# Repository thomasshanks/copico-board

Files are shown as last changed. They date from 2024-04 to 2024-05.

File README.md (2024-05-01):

# CoPiCo PCB KiCad Files

The CoPiCo is a cartridge for the Tandy Color Computer that adds WiFi to and
serves as a boot ROM for the system. It is based on the Raspberry Pi Pico W
microcontroller dev board, which includes onboard WiFi.

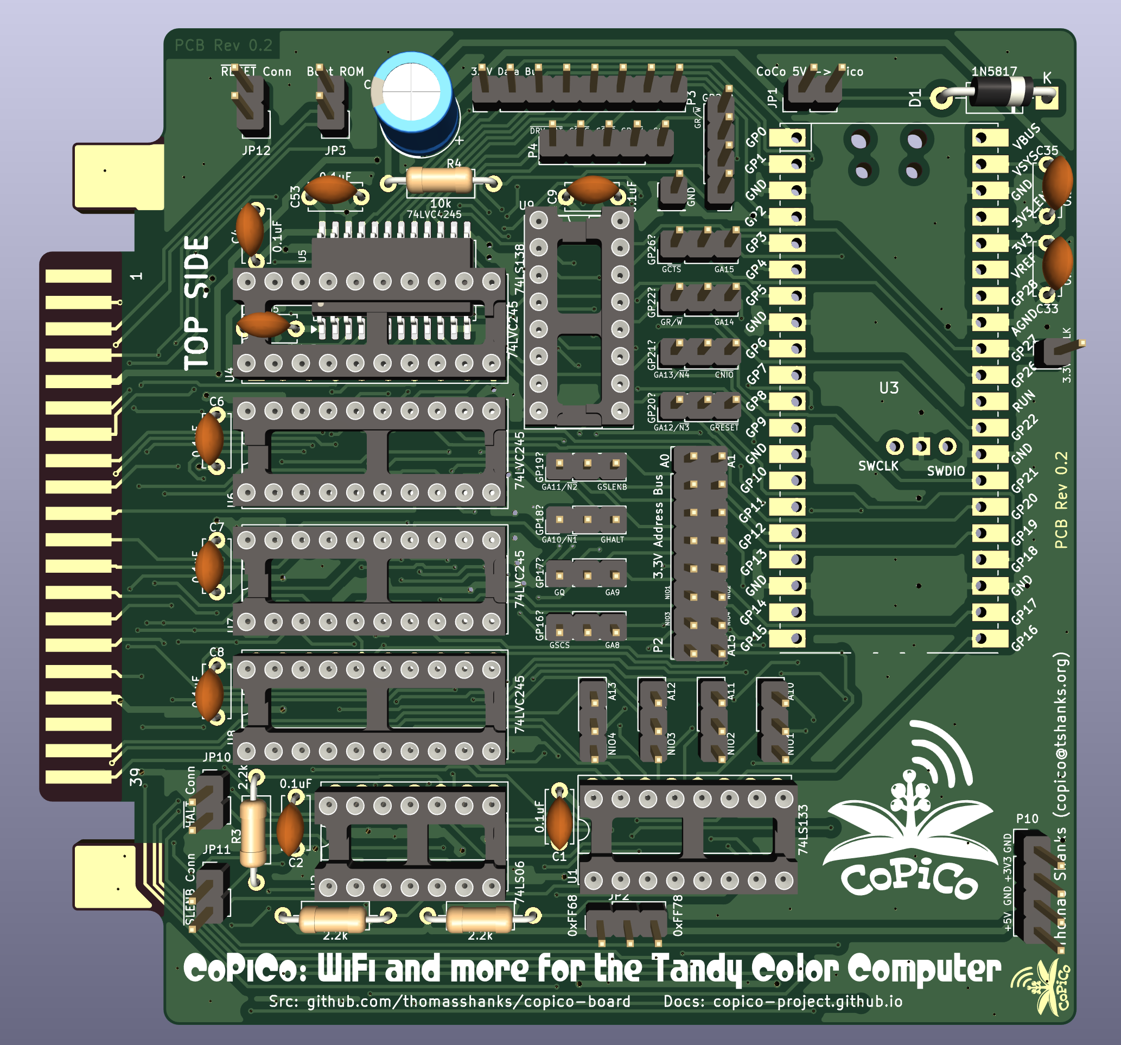
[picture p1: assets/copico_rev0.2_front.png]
copico_rev0.2_front


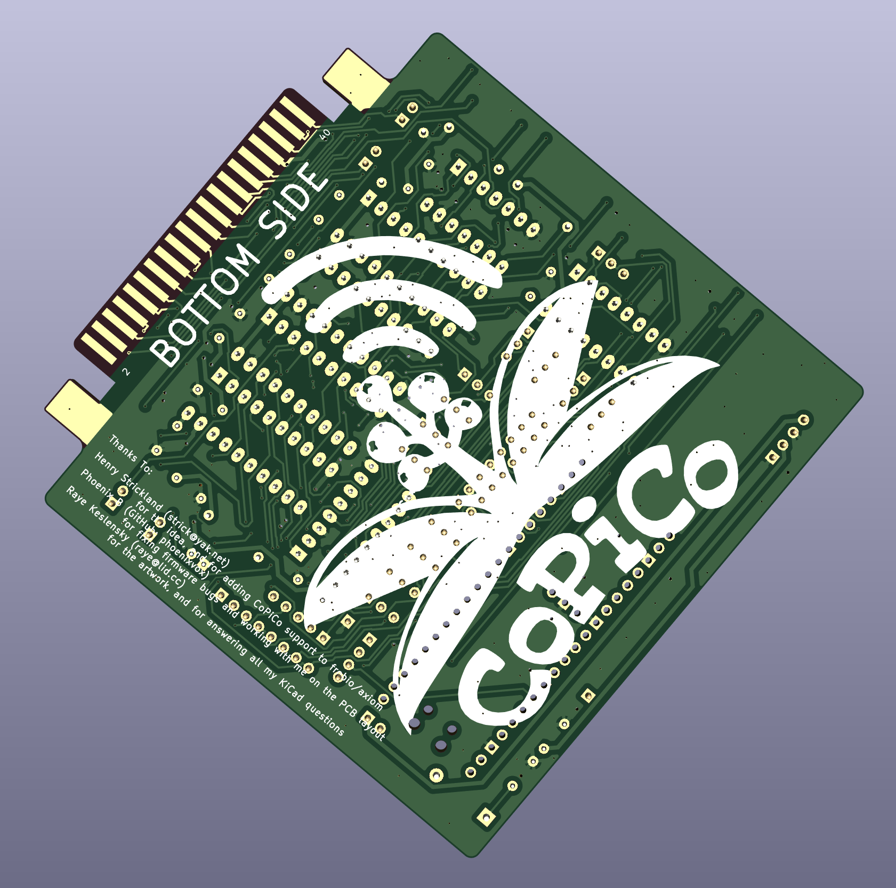
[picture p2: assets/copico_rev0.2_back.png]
copico_rev0.2_back


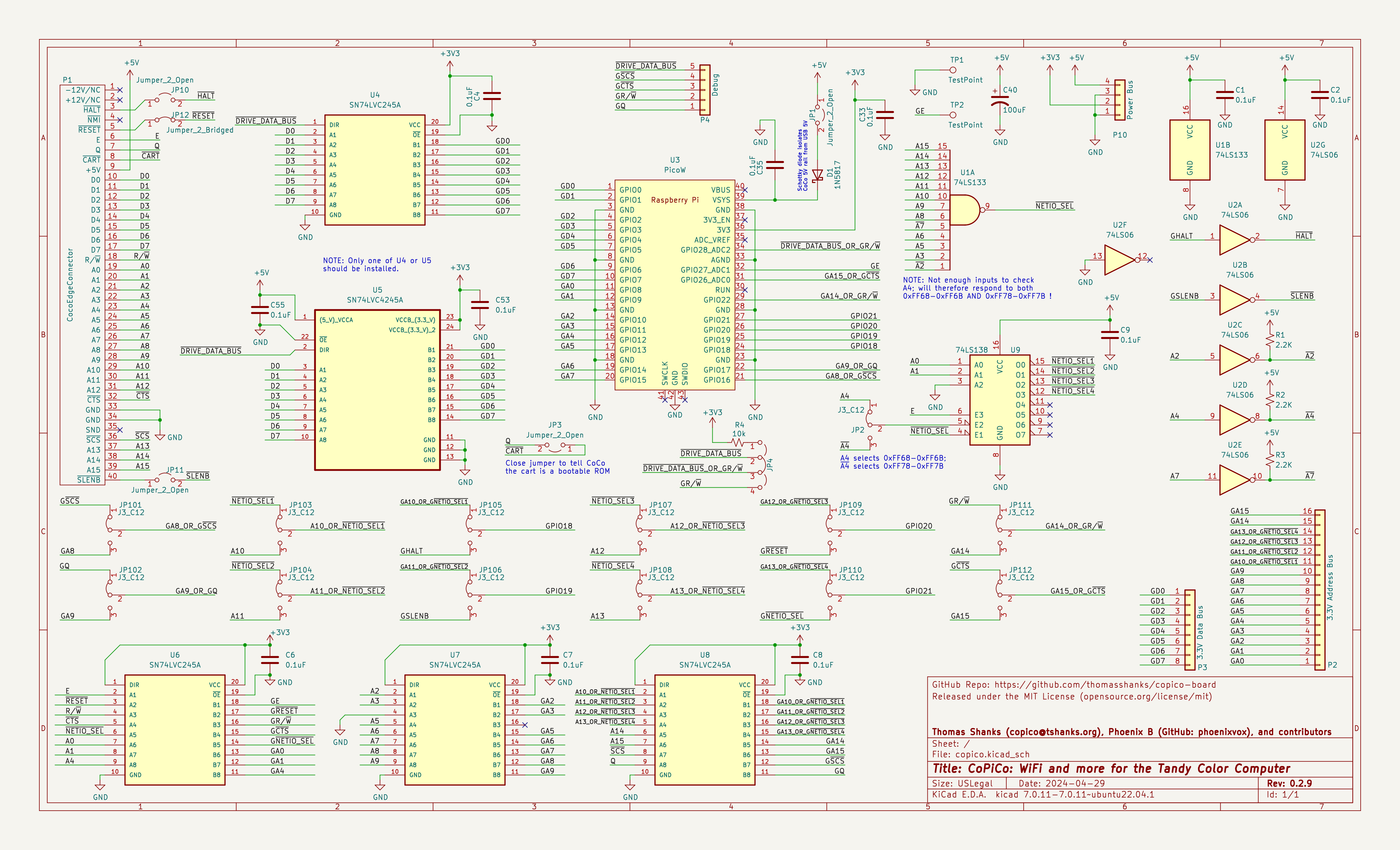
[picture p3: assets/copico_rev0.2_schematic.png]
copico_rev0.2_schematic

[copico_rev0.2_schematic_v0.2.9.pdf](assets/copico_rev0.2_schematic_v0.2.9.pdf)

## WiFi Connectivity

The firmware (see 'copico-firmware' repo) will behave more like a SPI WiFi
module or the WizNet chip (or perhaps both, depending on mode). It will, of
course, also allow listing and connecting to the desired WiFi network.

## ROM Emulation

CoPiCo will also support boot ROM emulation (initially just for a 1 KB ROM due
to limitations of first revision of the CoPiCo PCB). Henry Strickland
(@strickyak) plans to use this feature to load a version of his
"axiom" network boot ROM (see
https://github.com/strickyak/frobio/tree/main/frob3/booting).

## Other Future Capabilities

Future capabilities for the CoPiCo may include:
- VGA or HDMI output based on the captured contents of video RAM
- Logic capture / bus trace
- Remote debug, with breakpoints and watchpoints

## Stay Tuned to This Channel

Please star this repo and/or watch this space for updates as development
continues!

Thank you for being a part of the Retrocomputing community!

Thomas Shanks (copico@tshanks.org)

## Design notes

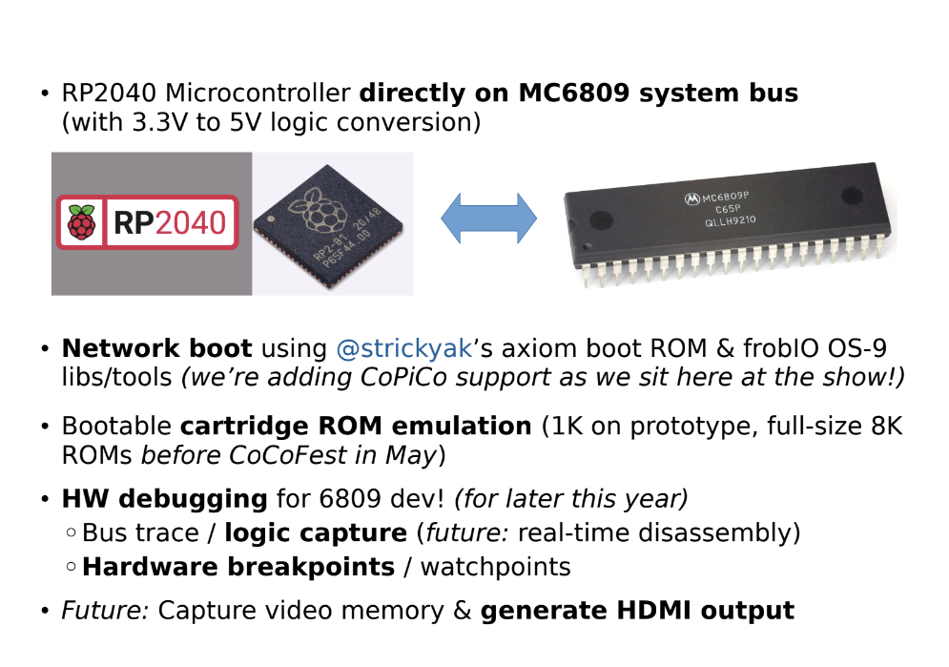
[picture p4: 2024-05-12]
assets/copico_slide.png

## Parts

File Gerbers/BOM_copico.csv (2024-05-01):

Ref | Qnty | Value | Cmp name | Footprint | Description | Vendor | Part
C1, C2, C4, C5, C8, C9, C33, C35, C73, C75 | 10 | 0.1uF | C | Capacitor_THT:C_Disc_D5.0mm_W2.5mm_P5.00mm | Ceramic THT Capacitor | AVX | SR215C104MAA
C40 | 1 | 100uF | C_Polarized | Capacitor_THT:CP_Radial_D7.5mm_P2.50mm | Electrolytic THT Capacitor | Panasonic | 16SEPC100MW
D1 | 1 |  | 1N5817 | Diode_THT:D_DO-41_SOD81_P10.16mm_Horizontal | 20V 1A Schottky Barrier Rectifier Diode, DO-41 | Major Brands | 1N5817
JP1, JP3, JP10, JP11 | 4 | Open | DIP_Jumper_Header_1x2 | Connector_PinHeader_2.54mm:PinHeader_1x02_P2.54mm_Vertical | Header, 100mil, single row, 1x2 | Jameco ValuePro | PH20-140S-6T
JP12 | 1 | Bridged12 | DIP_Jumper_Header_1x2 | Connector_PinHeader_2.54mm:PinHeader_1x02_P2.54mm_Vertical | Header, 100mil, single row, 1x2 | Jameco ValuePro | PH20-140S-6T
JP2, JP101, JP102, JP103, JP104, JP105, JP106, JP107, JP108, JP109, JP110, JP111, JP112 | 13 | Bridged12 | DIP_Jumper_Header_1x3 | Connector_PinHeader_2.54mm:PinHeader_1x03_P2.54mm_Vertical | Header, 100mil, single row, 1x3 | Jameco ValuePro | PH20-140S-6T
JP4 | 1 | Bridged23 | DIP_Jumper_Header_1x4 | Connector_PinHeader_2.54mm:PinHeader_1x04_P2.54mm_Vertical | Header, 100mil, single row, 1x4 | Jameco ValuePro | PH20-140S-6T
JP1, JP2, JP3, JP4, JP4, JP10, JP11, JP12, JP101, JP102, JP103, JP104, JP105, JP106, JP107, JP108, JP109, JP110, JP111, JP112 | 20 |  | DIP_Jumper_2_Pin | None | Plastic Jumper, 2-pin, 100mil DIP Spacing | TE Connectivity | 881545-1
P1 | 1 |  | DIP_Header_1x16 | Connector_PinHeader_2.54mm:PinHeader_1x16_P2.54mm_Vertical | Header, 100mil, single row, 1x16 | Jameco ValuePro | PH20-140S-6T
P2, P3 | 2 |  | DIP_Header_1x8 | Connector_PinHeader_2.54mm:PinHeader_1x08_P2.54mm_Vertical | Header, 100mil, single row, 1x8 | Jameco ValuePro | PH20-140S-6T
P4 | 1 |  | DIP_Header_1x5 | Connector_PinHeader_2.54mm:PinHeader_1x05_P2.54mm_Vertical | Header, 100mil, single row, 1x5 | Jameco ValuePro | PH20-140S-6T
P10 | 1 |  | DIP_Header_1x4 | Connector_PinHeader_2.54mm:PinHeader_1x04_P2.54mm_Vertical | Header, 100mil, single row, 1x4 | Jameco ValuePro | PH20-140S-6T
R1, R2, R3 | 3 | 2.2K | R_Small | Resistor_THT:R_Axial_DIN0207_L6.3mm_D2.5mm_P10.16mm_Horizontal | Resistor, 0.25W, Axial | Jameco ValuePro | CF1/4W222JRC
R4 | 1 | 10k | R_Small | Resistor_THT:R_Axial_DIN0207_L6.3mm_D2.5mm_P10.16mm_Horizontal | Resistor, 0.25W, Axial | Jameco ValuePro | RC0410K0JT
TP1, TP2 | 2 |  | DIP_Header_1x1 | Connector_PinHeader_2.54mm:PinHeader_1x01_P2.54mm_Vertical | Header, 100mil, single row, 1x1 | Jameco ValuePro | PH20-140S-6T
U1 | 1 |  | 74LS133N | Package_DIP:DIP-16_W7.62mm_LongPads | NAND 13-input | Motorola | SN74LS133N
U1, U9 | 2 |  | DIP-16_W300_Socket | Package_DIP:DIP-16_W7.62mm_LongPads |  | Jameco ValuePro | ICS-316-T
U2 | 1 |  | 74LS06N | Package_DIP:DIP-14_W7.62mm_LongPads | Inverter Open Collect | Major Brands | 74LS06N
U2 | 1 |  | DIP-14_W300_Socket | Package_DIP:DIP-14_W7.62mm_LongPads |  | Jameco ValuePro | ICS-314-T
U3 | 1 |  | PicoWH | RPi_Pico:RPi_PicoW_SMD_TH | RPi Pico W | RPi | Pico W
U3, U3 | 2 |  | DIP_Header_1x20 | Connector_PinHeader_2.54mm:PinHeader_1x20_P2.54mm_Vertical | Header, 100mil, single row, 1x20 | Jameco ValuePro | PH20-140S-6T
U3, U3 | 2 |  | SIP-20_Socket | Package_SIP:SIP-20_LongPads |  | Jameco ValuePro | G85-20-R
U4, U6, U7, U8 | 4 |  | SN74LVC245AN | Package_DIP:DIP-20_W7.62mm_LongPads |  | TI | SN74LVC245AN
U4, U6, U7, U8 | 4 |  | DIP-20_W300_Socket | Package_DIP:DIP-20_W7.62mm_LongPads |  | Adam Tech | ICS-320-T
U5 | 1 |  | SN74LVC4245A | Package_SO:SOIC-24W_7.5x15.4mm_P1.27mm |  | TI | SN74LVC4245ADWR
U9 | 1 |  | 74LS138N | Package_DIP:DIP-16_W7.62mm_LongPads | Decoder 3 to 8 active low outputs | TI | SN74LS138N

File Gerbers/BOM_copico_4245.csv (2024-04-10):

designator | quantity | value | pkg | desc | mpn | mount_type
C1, C2, C32, C4, C5, C73, C75, C8 | 8 | 0.1uF | C_Disc_D5.0mm_W2.5mm_P5.00mm | Ceramic Radial 0.1uF 10% 25+V LS:5mm |  | tht
C31 | 1 | 4.7uF | C_Rect_L5.0mm_W3.2mm_H5.00mm | Ceramic Radial 4.7uF 10% 25+V LS:5mm | FG28X5R1E475KRT06 | tht
C40 | 1 | 100uF | CP_Radial_D7.5mm_P2.50mm | Electrolytic Radial 100uF 20% 5000hr LS:2.5mm | ESL107M035AE3AA | tht
JP1, JP3 | 2 | 8JP2NC | PinHeader_2x08_P2.54mm_Vertical | M 2.54mm Header |  | tht
JP2 | 1 | J3_C12 | PinHeader_1x03_P2.54mm_Vertical | M 2.54mm Header |  | tht
P10 | 1 | Power Bus | PinHeader_1x04_P2.54mm_Vertical | M 2.54mm Header |  | tht
P2 | 1 | 5V Data Bus | PinHeader_1x08_P2.54mm_Vertical | M 2.54mm Header |  | tht
P3 | 1 | 3.3V Data Bus | PinHeader_1x08_P2.54mm_Vertical | M 2.54mm Header |  | tht
P4 | 1 | 5V Address Bus | PinHeader_1x16_P2.54mm_Vertical | M 2.54mm Header |  | tht
P5 | 1 | 3.3V Address Bus | PinHeader_1x16_P2.54mm_Vertical | M 2.54mm Header |  | tht
R1, R2 | 2 | 4.7k | R_Axial_DIN0207_L6.3mm_D2.5mm_P10.16mm_Horizontal | Film Resistor Axial 1/4w 5% |  | tht
U1 | 1 | DIP-16 SKT | DIP-16_W7.62mm_LongPads | 16P DUAL WIPE DIPSKT | 4816-3000-CP | tht
U2 | 1 | DIP-14 SKT | DIP-14_W7.62mm_LongPads | 14P DUAL WIPE DIPSKT | 4814-3000-CP | tht
U3 | 2 | 2ea / SIP-20 SKT | SIP-20_LongPads | PAIR OF STANDRD SOLDER TAIL SIP SOCKETS 5mm Height |  | tht
U4, U5, U8 | 3 | DIP-20 SKT | DIP-20_W7.62mm_LongPads | 20P DUAL WIPE DIPSKT |  | tht
U6 | 1 | dnp | dnp | dnp |  | tht
U7 | 1 | 74LVC4245A | SOIC127P1030X265-24N | Bus Transceivers Octal Bus Trncvr & 3.3-5V W/3-St Otpt | SN74LVC4245ADWR | tht

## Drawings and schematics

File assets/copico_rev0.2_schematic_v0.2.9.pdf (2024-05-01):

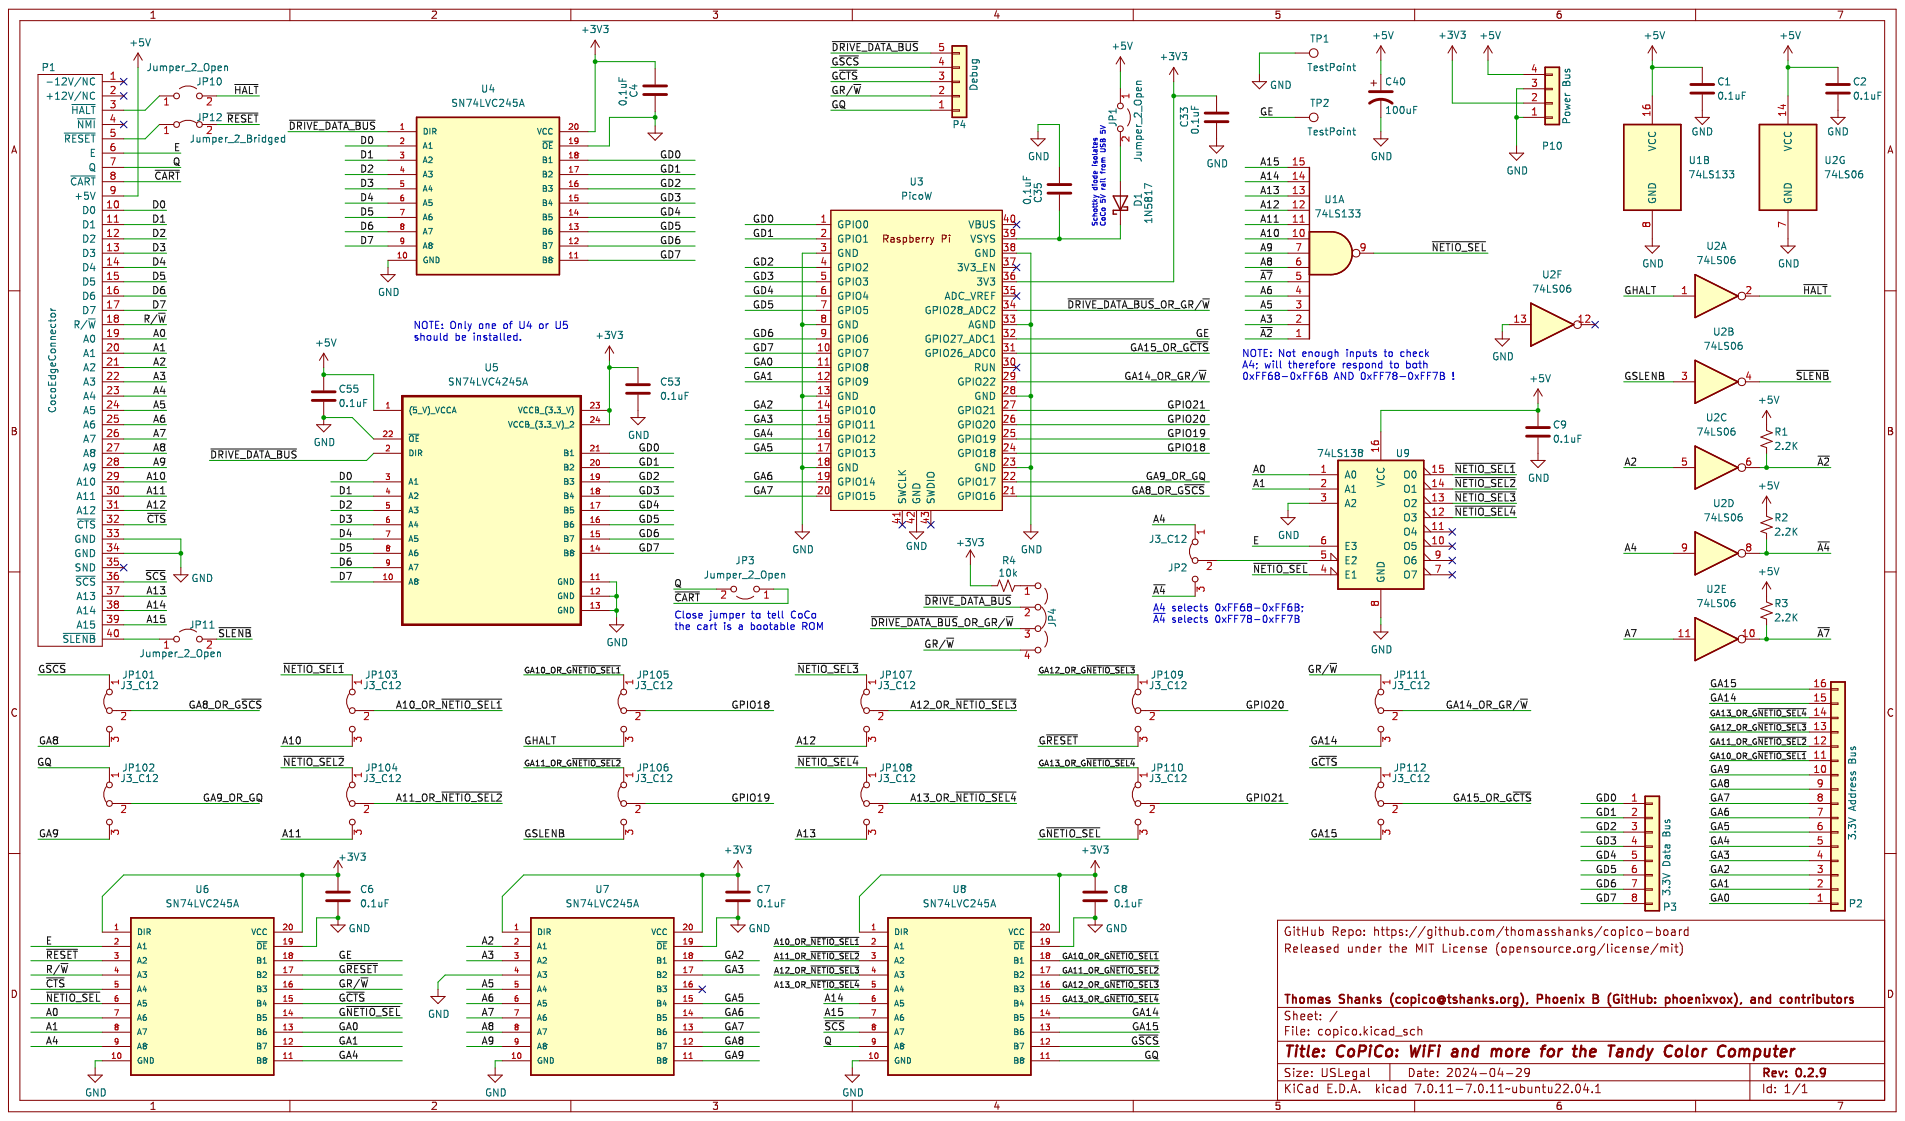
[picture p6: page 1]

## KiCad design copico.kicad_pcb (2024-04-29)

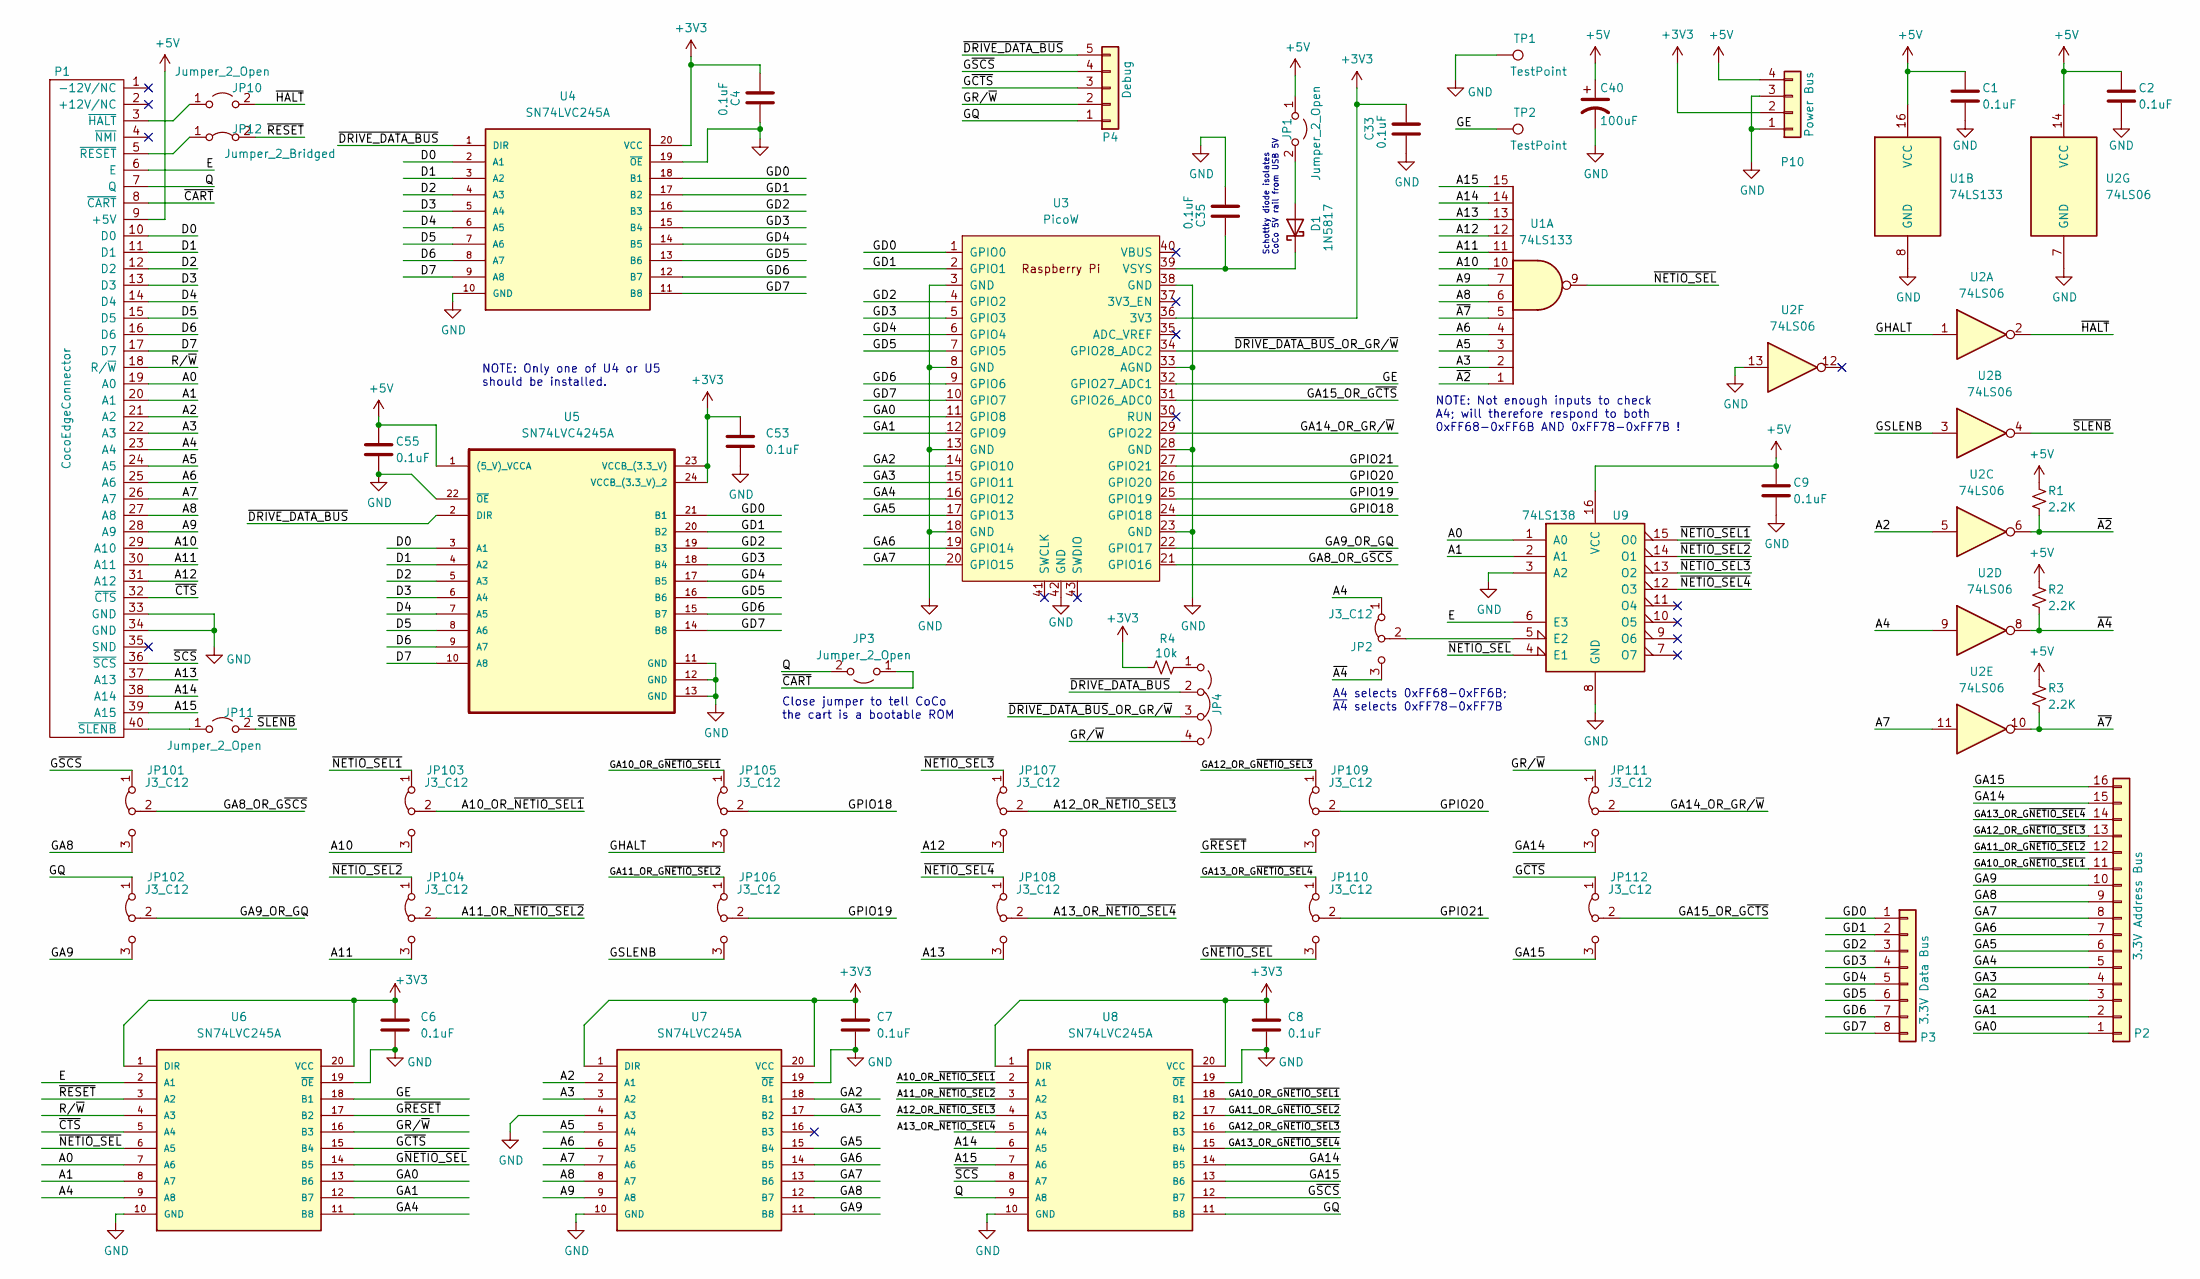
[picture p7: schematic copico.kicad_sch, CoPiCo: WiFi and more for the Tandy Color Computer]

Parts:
C1, C2, C4, C6, C7, C8, C9, C33, C35, C53, C55: 0.1uF; C_Disc_D5.0mm_W2.5mm_P5.00mm
C40: 100uF; CP_Radial_D7.5mm_P2.50mm
D1: 1N5817; D_DO-41_SOD81_P10.16mm_Horizontal
JP1, JP3, JP10, JP11: Jumper_2_Open; PinHeader_1x02_P2.54mm_Vertical
JP2, JP101, JP102, JP103, JP104, JP105, JP106, JP107, JP108, JP109, JP110, JP111, JP112: J3_C12; PinHeader_1x03_P2.54mm_Vertical
JP4: jp_ser_4pin_23cl; PinHeader_1x04_P2.54mm_Vertical
JP12: Jumper_2_Bridged; PinHeader_1x02_P2.54mm_Vertical
P1: CocoEdgeConnector; CocoCardEdge
P2: 3.3V Address Bus; PinHeader_1x16_P2.54mm_Vertical
P3: 3.3V Data Bus; PinHeader_1x08_P2.54mm_Vertical
P4: Debug; PinHeader_1x05_P2.54mm_Vertical
P10: Power Bus; PinHeader_1x04_P2.54mm_Vertical
R1, R2, R3: 2.2K; R_Axial_DIN0207_L6.3mm_D2.5mm_P10.16mm_Horizontal
R4: 10k; R_Axial_DIN0207_L6.3mm_D2.5mm_P10.16mm_Horizontal
TP1, TP2: TestPoint; PinHeader_1x01_P2.54mm_Vertical
U1: 74LS133; DIP-16_W7.62mm_LongPads
U2: 74LS06; DIP-14_W7.62mm_LongPads
U3: PicoW; RPi_PicoW_SMD_TH
U4, U6, U7, U8: SN74LVC245A; DIP20-2.54-26.2X7.62MM; MPN SN74LVC245AN
U5: SN74LVC4245A; SOIC-24W_7.5x15.4mm_P1.27mm
U9: 74LS138; DIP-16_W7.62mm_LongPads

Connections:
+3V3: C4.2, C6.1, C7.1, C8.1, C33.1, C53.1, P10.2, R4.1, U3.36 (3V3), U4.20 (VCC), U5.23 (VCCB_(3.3_V)), U5.24 (VCCB_(3.3_V)_2), U6.1 (DIR), U6.20 (VCC), U7.1 (DIR), U7.20 (VCC), U8.1 (DIR), U8.20 (VCC)
+5V: C1.1, C2.1, C9.1, C40.1, C55.1, JP1.1 (A), P1.9 (+5V), P10.4, R1.1, R2.1, R3.1, U1.16 (VCC), U2.14 (VCC), U5.1 ((5_V)_VCCA), U9.16 (VCC)
/A0: P1.19 (A0), U6.7 (A6), U9.1 (A0)
/A1: P1.20 (A1), U6.8 (A7), U9.2 (A1)
/A2: P1.21 (A2), U2.5, U7.2 (A1)
/A3: P1.22 (A3), U1.2, U7.3 (A2)
/A4: JP2.1 (A), P1.23 (A4), U2.9, U6.9 (A8)
/A5: P1.24 (A5), U1.3, U7.5 (A4)
/A6: P1.25 (A6), U1.4, U7.6 (A5)
/A7: P1.26 (A7), U2.11, U7.7 (A6)
/A8: P1.27 (A8), U1.6, U7.8 (A7)
/A9: P1.28 (A9), U1.7, U7.9 (A8)
/A10: JP103.3 (B), P1.29 (A10), U1.10
/A10_OR_~NETIO_SEL1: JP103.2 (C), U8.2 (A1)
/A11: JP104.3 (B), P1.30 (A11), U1.11
/A11_OR_~NETIO_SEL2: JP104.2 (C), U8.3 (A2)
/A12: JP107.3 (B), P1.31 (A12), U1.12
/A12_OR_~NETIO_SEL3: JP107.2 (C), U8.4 (A3)
/A13: JP108.3 (B), P1.37 (A13), U1.13
/A13_OR_~NETIO_SEL4: JP108.2 (C)
/A14: P1.38 (A14), U1.14, U8.6 (A5)
/A15: P1.39 (A15), U1.15, U8.7 (A6)
/D0: P1.10 (D0), U4.2 (A1), U5.3 (A1)
/D1: P1.11 (D1), U4.3 (A2), U5.4 (A2)
/D2: P1.12 (D2), U4.4 (A3), U5.5 (A3)
/D3: P1.13 (D3), U4.5 (A4), U5.6 (A4)
/D4: P1.14 (D4), U4.6 (A5), U5.7 (A5)
/D5: P1.15 (D5), U4.7 (A6), U5.8 (A6)
/D6: P1.16 (D6), U4.8 (A7), U5.9 (A7)
/D7: P1.17 (D7), U4.9 (A8), U5.10 (A8)
/E: P1.6 (E), U6.2 (A1), U9.6 (E3)
/GA0: P2.1, U3.11 (GPIO8), U6.13 (B6)
/GA1: P2.2, U3.12 (GPIO9), U6.12 (B7)
/GA2: P2.3, U3.14 (GPIO10), U7.18 (B1)
/GA3: P2.4, U3.15 (GPIO11), U7.17 (B2)
/GA4: P2.5, U3.16 (GPIO12), U6.11 (B8)
/GA5: P2.6, U3.17 (GPIO13), U7.15 (B4)
/GA6: P2.7, U3.19 (GPIO14), U7.14 (B5)
/GA7: P2.8, U3.20 (GPIO15), U7.13 (B6)
/GA8: JP101.3 (B), P2.9, U7.12 (B7)
/GA8_OR_G~SCS: JP101.2 (C), U3.21 (GPIO16)
/GA9: JP102.3 (B), P2.10, U7.11 (B8)
/GA9_OR_GQ: JP102.2 (C), U3.22 (GPIO17)
/GA10_OR_G~NETIO_SEL1: JP105.1 (A), P2.11, U8.18 (B1)
/GA11_OR_G~NETIO_SEL2: JP106.1 (A), P2.12, U8.17 (B2)
/GA12_OR_G~NETIO_SEL3: JP109.1 (A), P2.13, U8.16 (B3)
/GA13_OR_G~NETIO_SEL4: JP110.1 (A), P2.14, U8.15 (B4)
/GA14: JP111.3 (B), P2.15, U8.14 (B5)
/GA14_OR_GR/~W: JP111.2 (C), U3.29 (GPIO22)
/GA15: JP112.3 (B), P2.16, U8.13 (B6)
/GA15_OR_G~CTS: JP112.2 (C), U3.31 (GPIO26_ADC0)
/GD0: P3.1, U3.1 (GPIO0), U4.18 (B1), U5.21 (B1)
/GD1: P3.2, U3.2 (GPIO1), U4.17 (B2), U5.20 (B2)
/GD2: P3.3, U3.4 (GPIO2), U4.16 (B3), U5.19 (B3)
/GD3: P3.4, U3.5 (GPIO3), U4.15 (B4), U5.18 (B4)
/GD4: P3.5, U3.6 (GPIO4), U4.14 (B5), U5.17 (B5)
/GD5: P3.6, U3.7 (GPIO5), U4.13 (B6), U5.16 (B6)
/GD6: P3.7, U3.9 (GPIO6), U4.12 (B7), U5.15 (B7)
/GD7: P3.8, U3.10 (GPIO7), U4.11 (B8), U5.14 (B8)
/GE: TP2.1, U3.32 (GPIO27_ADC1), U6.18 (B1)
/GHALT: JP105.3 (B), U2.1
/GPIO18: JP105.2 (C), U3.24 (GPIO18)
/GPIO19: JP106.2 (C), U3.25 (GPIO19)
/GPIO20: JP109.2 (C), U3.26 (GPIO20)
/GPIO21: JP110.2 (C), U3.27 (GPIO21)
/GQ: JP102.1 (A), P4.1, U8.11 (B8)
/GR/~W: JP4.4 (D), JP111.1 (A), P4.2, U6.16 (B3)
/GSLENB: JP106.3 (B), U2.3
/G~CTS: JP112.1 (A), P4.3, U6.15 (B4)
/G~NETIO_SEL: JP110.3 (B), U6.14 (B5)
/G~RESET: JP109.3 (B), U6.17 (B2)
/G~SCS: JP101.1 (A), P4.4, U8.12 (B7)
/Q: JP3.2 (B), P1.7 (Q), U8.9 (A8)
/R/~W: P1.18 (R/~W), U6.4 (A3)
/~A2: R1.2, U1.1, U2.6
/~A4: JP2.3 (B), R2.2, U2.8
/~A7: R3.2, U1.5, U2.10
/~CART: JP3.1 (A), P1.8 (~CART)
/~CTS: P1.32 (~CTS), U6.5 (A4)
/~DRIVE_DATA_BUS: JP4.2 (B), P4.5, U4.1 (DIR), U5.2 (DIR)
/~DRIVE_DATA_BUS_OR_GR/~W: JP4.3 (C), U3.34 (GPIO28_ADC2)
/~HALT: JP10.2 (B), U2.2
/~NETIO_SEL1: JP103.1 (A), U9.15 (O0)
/~NETIO_SEL2: JP104.1 (A), U9.14 (O1)
/~NETIO_SEL3: JP107.1 (A), U9.13 (O2)
/~NETIO_SEL4: JP108.1 (A), U9.12 (O3)
/~NETIO_SEL: U1.9, U6.6 (A5), U9.4 (E1)
/~RESET: JP12.2 (B), U6.3 (A2)
/~SCS: P1.36 (~SCS), U8.8 (A7)
/~SLENB: JP11.2 (B), U2.4
GND: C1.2, C2.2, C4.1, C6.2, C7.2, C8.2, C9.2, C33.2, C35.2, C40.2, C53.2, C55.2, P1.33 (GND), P1.34 (GND), P10.1, P10.3, TP1.1, U1.8 (GND), U2.7 (GND), U2.13, U3.3 (GND), U3.8 (GND), U3.13 (GND), U3.18 (GND), U3.23 (GND), U3.28 (GND), U3.33 (AGND), U3.38 (GND), U3.42 (GND), U4.10 (GND), U4.19 (~OE), U5.11 (GND), U5.12 (GND), U5.13 (GND), U5.22 (~OE), U6.10 (GND), U6.19 (~OE), U7.4 (A3), U7.10 (GND), U7.19 (~OE), U8.10 (GND), U8.19 (~OE), U9.3 (A2), U9.8 (GND)
unnamed: D1.2 (A), JP1.2 (B)
unnamed: C35.1, D1.1 (K), U3.39 (VSYS)
unnamed: JP2.2 (C), U9.5 (E2)
unnamed: JP4.1 (A), R4.2
unnamed: JP10.1 (A), P1.3 (~HALT)
unnamed: JP11.1 (A), P1.40 (~SLENB)
unnamed: JP12.1 (A), P1.5 (~RESET)

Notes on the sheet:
NOTE: Not enough inputs to check A4; will therefore respond to both 0xFF68-0xFF6B AND 0xFF78-0xFF7B !
NOTE: Only one of U4 or U5 should be installed.
Schottky diode isolates CoCo 5V rail from USB 5V
A4 selects 0xFF68-0xFF6B; ~{A4} selects 0xFF78-0xFF7B
Close jumper to tell CoCo the cart is a bootable ROM

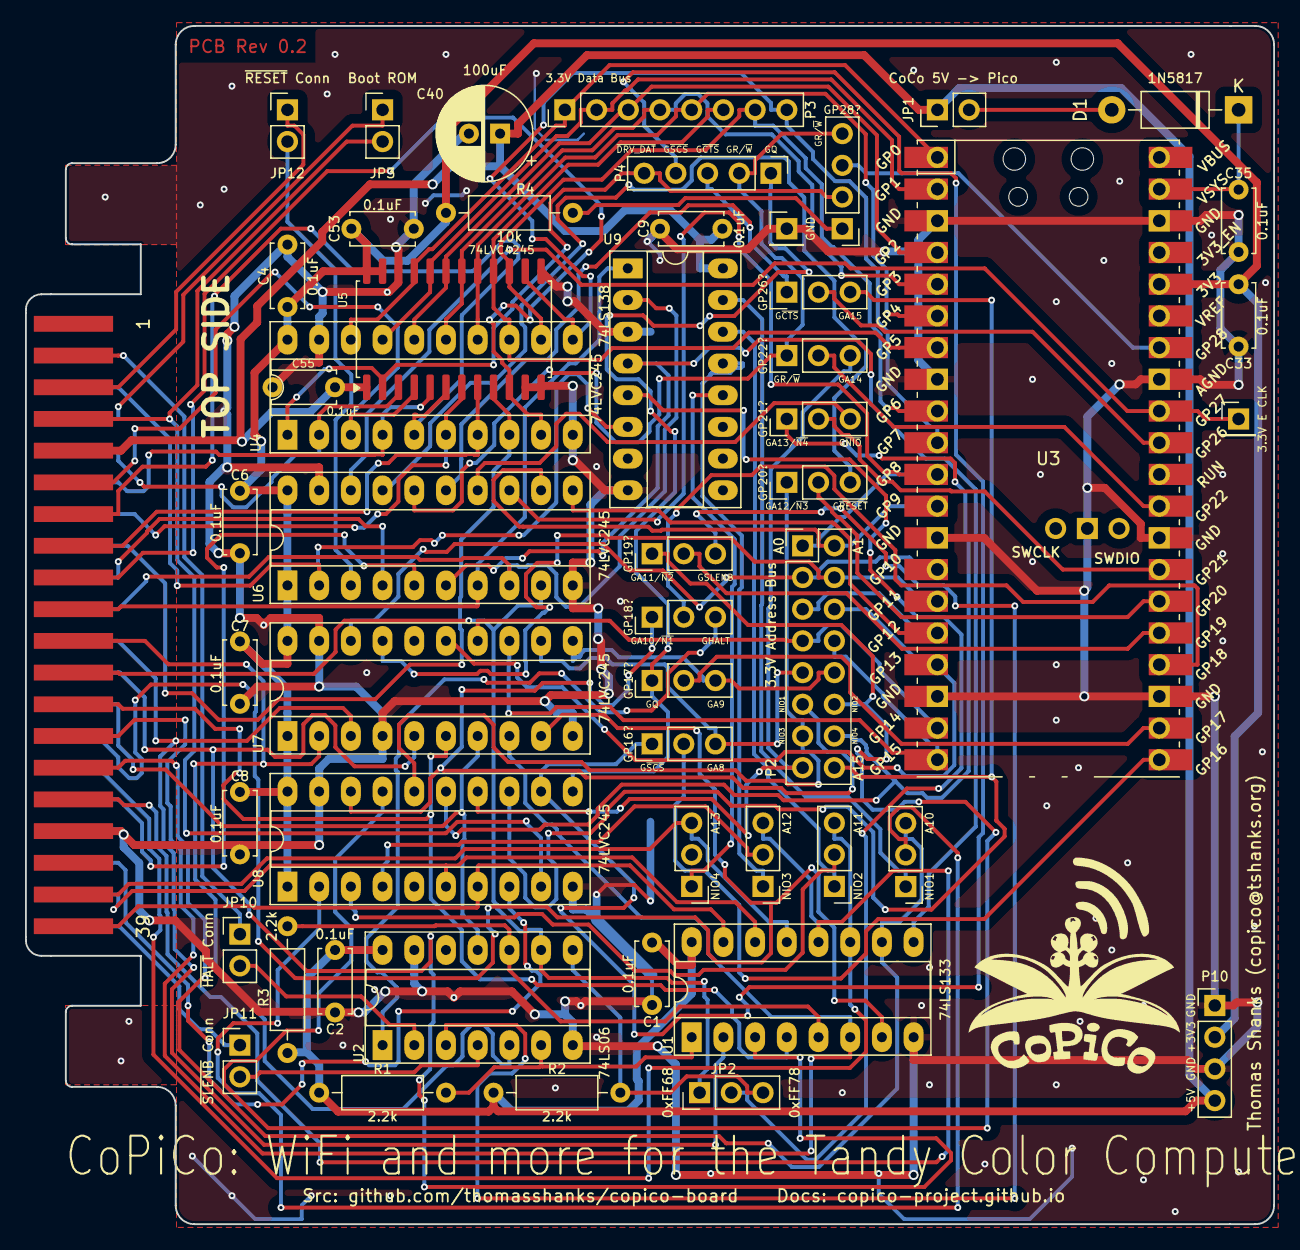
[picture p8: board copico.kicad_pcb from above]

Board: 2 copper layers, 100.0 x 96.0 mm, 54 parts (0 on the bottom side), 97 nets.

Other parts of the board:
G0: LOGO; logo_small
G2: LOGO; logo_medium

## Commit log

2024-02-16 Initial commit of PCB Rev 0.1 as built
    [copico-B_Cu.gbl, copico-B_Mask.gbs, copico-B_Paste.gbp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]
2024-02-18 Add PCB images to README.md
2024-02-18 Update README.md with schematic PNG and PDF
2024-02-18 Correct signal naming on schematic & URL on PCB
    [copico.kicad_pcb, copico.kicad_sch]
2024-03-20 Update component values to match reality
    - Update component values to match what we actually used on the board.
    - Add an additional decoupling capacitor for the PicoW to the schematic. This
    capacitor is not yet laid out onto the actual board.
    - Take the bar off of the GHALT and GSLENB signals since they are actually
    active high, not active low.
    - Additional schematic cleanup.
    [copico.kicad_sch]
2024-03-26 Update silkscreen with component values
    I accidentally left the component value silkscreening off the first run of the
    board. Add these back, as well as adding some labels to the jumpers and such.
    Update PCB Rev in solder mask to 0.1a, but leave the copper layer PCB Rev at
    0.1 since that layer has not changed.
    [copico.kicad_pcb]
2024-04-02 Update Gerbers with those from Rev 0.1a PCBWay run
    [copico-B_Cu.gbr, copico-B_Mask.gbr, copico-B_Paste.gbp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]
2024-04-10 Add handwritten Bill of Materials
    [BOM_copico.csv, BOM_copico_4245.csv]
2024-04-18 Update schematic to REV 2
    The REV 2 design:
    - allows the CoCo to power the PicoW via a Schottky diode, which prevents
    backfeeding one power supply from the other
    - moves the address decode for the NETIO feature out of the PicoW firmware into
    discrete 74LS logic in order to allow it to respond using only PIO and DMA
    [copico.kicad_sch]
2024-04-19 FIXME: need pull-up R when DRIVE_DATA_BUS floating
    Add a FIXME that indicates the need for DRIVE_DATA_BUS to be pulled high when
    the GPIO28 jumper is set to send GR//W to the PicoW instead of getting
    DRIVE_DATA_BUS from the PicoW on that GPIO
    [copico.kicad_sch]
2024-04-29 Update BOM_copico.csv for Rev 2 PCB
    [BOM_copico.csv]
2024-04-29 Update PCB layout with Rev 0.2 schematic changes
    [copico.kicad_pcb, copico.kicad_sch]
2024-04-29 Assigned Nets, added pullup for drive_data_bus
    Assigned Netclasses for PWR, GND, and Addresses(3.3V only).
    Added pullup resistor to drive_data_bus when jumper changed to
    disconnected from pi
    Added 4pin series jumper with custom symbol to connect the
    pullup resistor.
    [copico.kicad_sch]
2024-04-29 Changed some capacitors and labels
    [copico.kicad_sch]
2024-05-01 Update README.md with Rev 0.2 PCB images/schematic
2024-05-01 Update BOM with actual parts ordered for Rev 0.2
    [BOM_copico.csv]

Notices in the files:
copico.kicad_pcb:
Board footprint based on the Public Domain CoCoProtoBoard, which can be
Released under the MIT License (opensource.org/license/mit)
